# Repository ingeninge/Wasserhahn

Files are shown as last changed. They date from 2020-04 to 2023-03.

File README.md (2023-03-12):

# Wasserhahn

ATTENTION! This repository is only for testing! No production, and never will be.

MQTT controlled Motor Bulb Valve ESP8266 Arduino
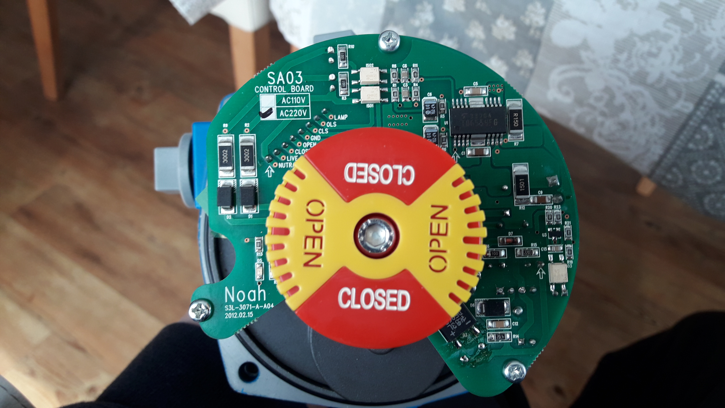
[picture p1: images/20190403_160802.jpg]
Image of the motor driver

Manufactor is END. Here is a link to the Datasheet: https://shop.end.de/armaturen/antriebe-und-zubehoer/elektrische-antriebe/ne034100-elektrischer-schwenkantrieb-30nm-230v-ac

Since my water tap in the garden was leaking and the repair would have included ripping down the building bricks, I asked a friend to build in a ball valve. 
On this I could mount a motor to open and close the garden water tap.
To control the motor I use a ESP8266-12 (WROOM-02) and two relays. The ESP uses 2 Inputs and 2 Outputs.
The schematic can be found in the folder images.
The Inputs are from the auxiliary isolated contacts from the motor. The contacts are closed ONLY at the end position of each turn.br>If both are open the valve is in between open and close.
The Outputs are controlling two relays. One for opening and one for closing the valve. The outputs are held active for 90 seconds.
<br>MQTT- protocol is used to control the garden water tap remotely.
First idea was to let it work with an Arduino Sketch, witch you can find in the sources. But then I figured out how to set up Tasmota to work with this Board and Motor. The workaround is: Tasmota [https://github.com/arendst/Tasmota] (I use Version 7.1) controls 2 relays - one for Opening and one for Closing the tap. The downside is, you will have to use two buttons or configure node-red with a function to control the state and switch between the states.<br>
For Programming see https://www.forward.com.au/pfod/ESP8266/GPIOpins/index.html GPIO0 and RST are on Jumper J5. GPIO2 is permanently pulled up via R8.
Todo: Remove copper under the antenna! Enable access to GPIO15 for programming mode or pull low permanent. update mill and drill files, mill, solder and test the layout. Release to public

The settings for Tasmota can be found in the Wiki https://github.com/ingeninge/Wasserhahn/wiki

BTW: I can control the bulb valve with a remote control in the garden, so I don't have to pull out my mobile to open the tap. [Remote control for Wasserhahn](https://github.com/ingeninge/ESP-Watertap-Remote)

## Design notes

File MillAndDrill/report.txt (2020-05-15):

Plot file "/home/ingmar/Programmieren/Wasserhahn/MillAndDrill/Wasserhahn-B_Cu.gbl" created.
Plot file "/home/ingmar/Programmieren/Wasserhahn/MillAndDrill/Wasserhahn-Edge_Cuts.gm1" created.

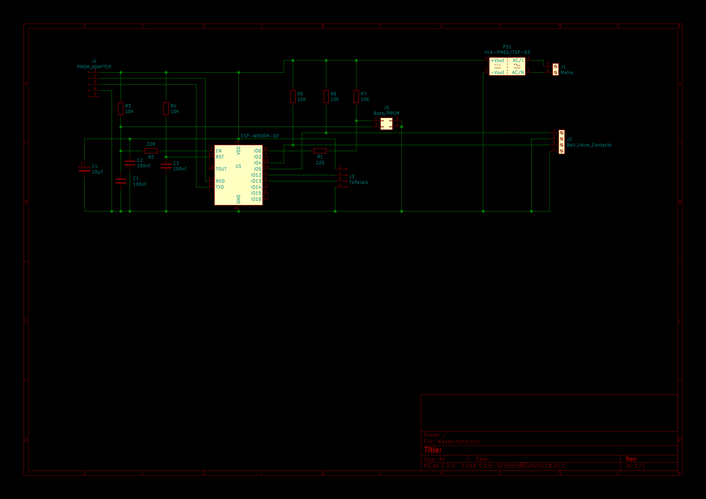
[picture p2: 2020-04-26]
images/Wasserhahn.sch.png

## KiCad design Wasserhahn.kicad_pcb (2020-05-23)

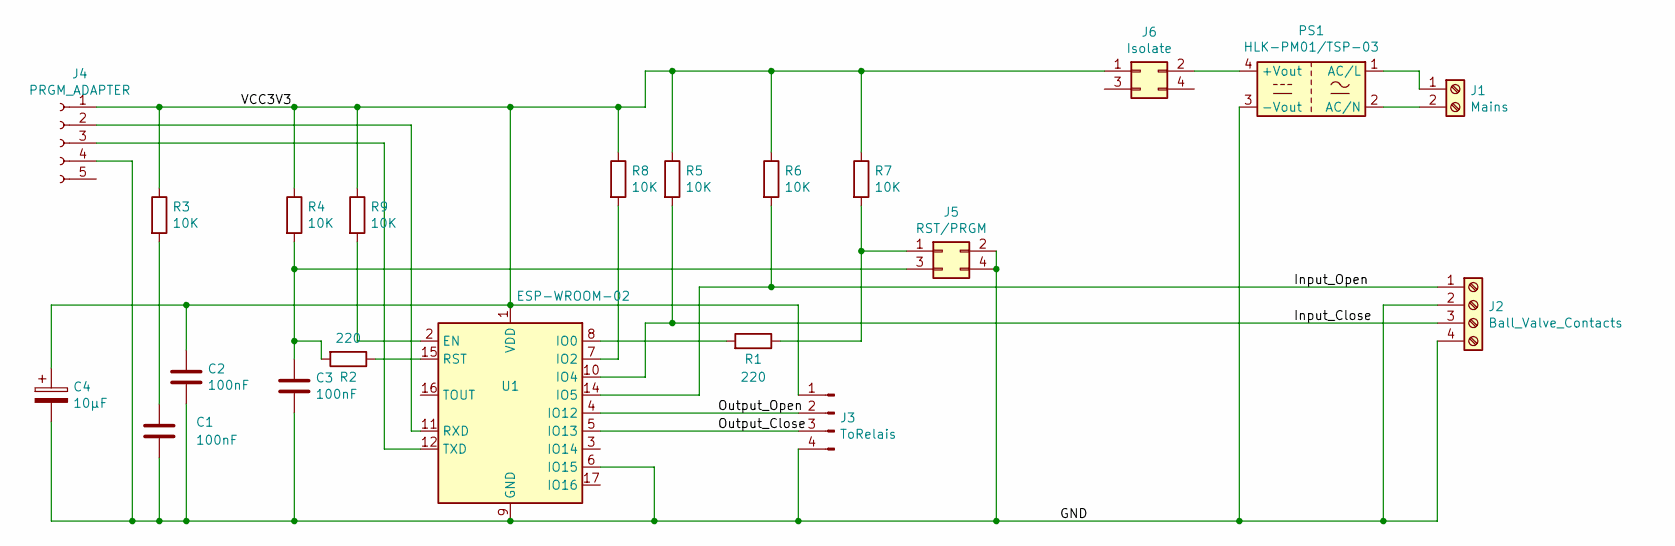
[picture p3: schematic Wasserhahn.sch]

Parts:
C1, C2, C3: 100nF; CP_Radial_D4.0mm_P2.00mm
C4: 10µF; CP_Radial_D6.3mm_P2.50mm
J1: Mains; TerminalBlock_Phoenix_PT-1,5-2-5.0-H_1x02_P5.00mm_Horizontal
J2: Ball_Valve_Contacts; TerminalBlock_Phoenix_PT-1,5-4-5.0-H_1x04_P5.00mm_Horizontal
J3: ToRelais; PinHeader_1x04_P2.54mm_Vertical
J4: PRGM_ADAPTER; PinHeader_1x05_P2.54mm_Vertical
J5: RST/PRGM; PinHeader_2x02_P2.54mm_Vertical
J6: Isolate; PinHeader_2x02_P2.54mm_Vertical
PS1: HLK-PM01/TSP-03; Converter_ACDC_HiLink_HLK-PMxx
R1, R2: 220; R_Axial_DIN0207_L6.3mm_D2.5mm_P10.16mm_Horizontal
R3, R4, R5, R6, R7, R8, R9: 10K; R_Axial_DIN0207_L6.3mm_D2.5mm_P10.16mm_Horizontal
U1: ESP-WROOM-02

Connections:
/GND: C1.2, C2.2, C3.2, C4.2, J2.2, J2.4, J3.4, J4.4, J5.2, J5.4, PS1.3 (-Vout), U1.6 (IO15), U1.9 (GND), U1.13 (GND), U1.18 (GND), U1.19 (GND)
/Input_Close: J2.3, R5.2, U1.10 (IO4)
/Input_Open: J2.1, R6.2, U1.14 (IO5)
/Output_Close: J3.3, U1.5 (IO13)
/Output_Open: J3.2, U1.4 (IO12)
/VCC3V3: C2.1, C4.1, J3.1, J4.1, J6.1, R3.1, R4.1, R5.1, R6.1, R7.1, R8.1, R9.1, U1.1 (VDD)
unnamed: C1.1, R3.2
unnamed: C3.1, J5.3, R2.2, R4.2
unnamed: J1.1, PS1.1 (AC/L)
unnamed: J1.2, PS1.2 (AC/N)
unnamed: J4.2, U1.11 (RXD)
unnamed: J4.3, U1.12 (TXD)
unnamed: J5.1, R1.1, R7.2
unnamed: J6.2, PS1.4 (+Vout)
unnamed: R1.2, U1.8 (IO0)
unnamed: R2.1, U1.15 (RST)
unnamed: R8.2, U1.7 (IO2)
unnamed: R9.2, U1.2 (EN)

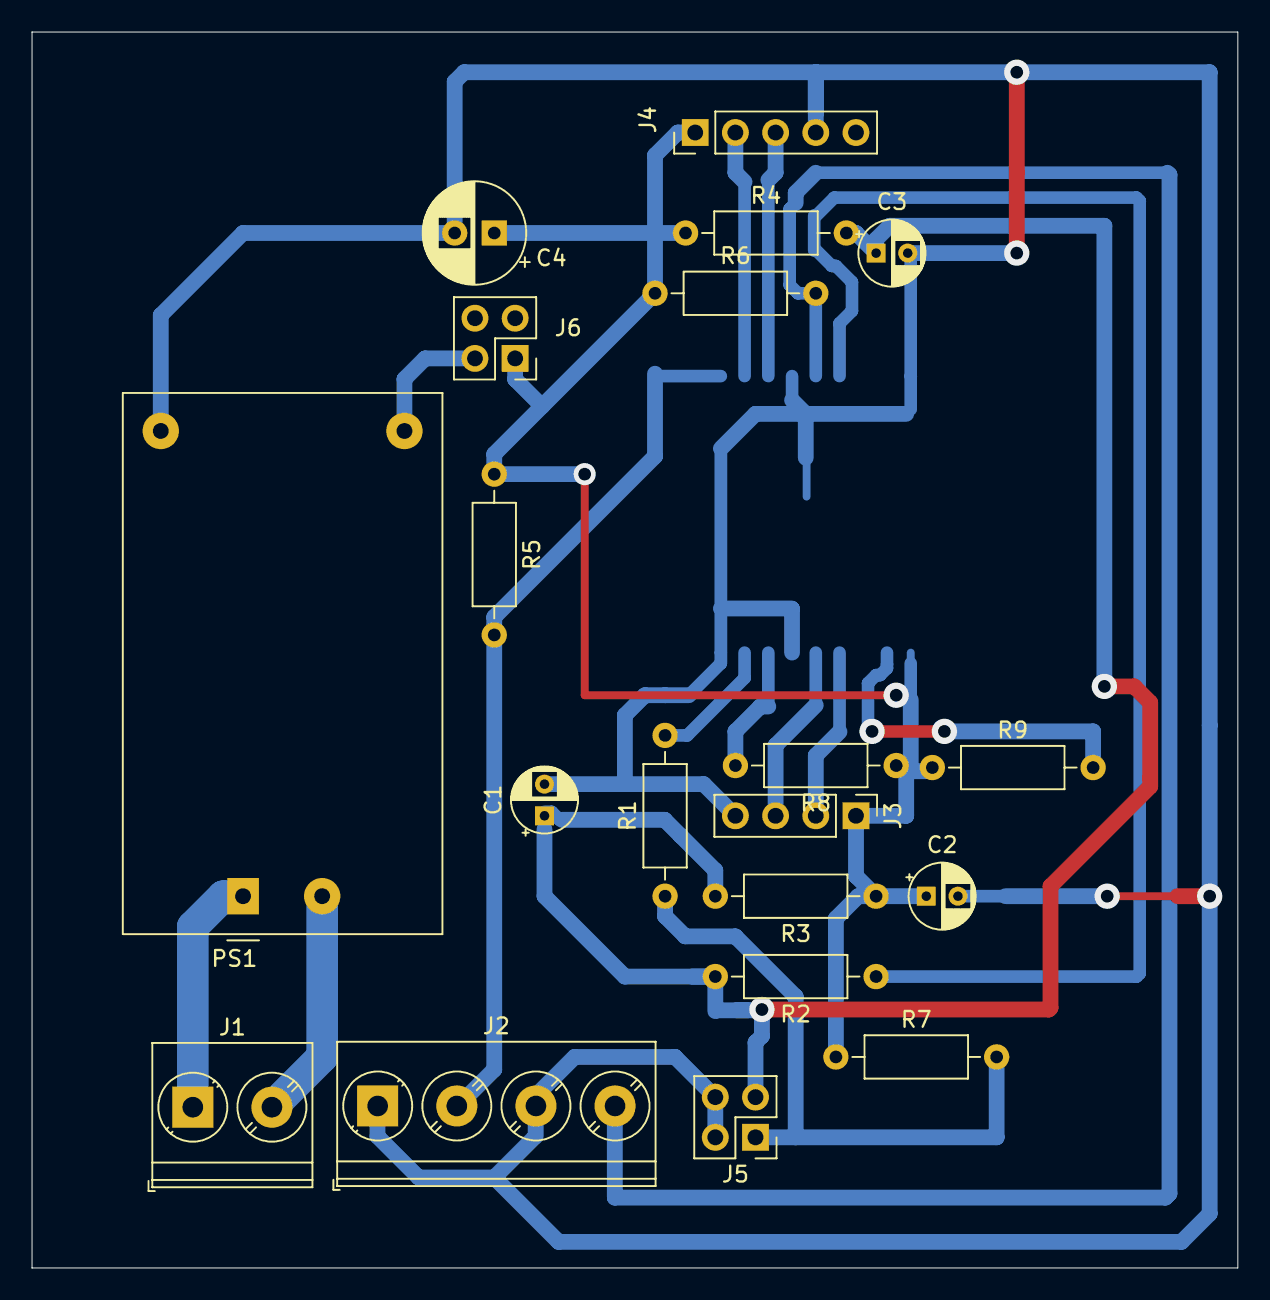
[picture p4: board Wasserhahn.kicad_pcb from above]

Board: 2 copper layers, 76.2 x 78.1 mm, 21 parts (1 on the bottom side), 18 nets.

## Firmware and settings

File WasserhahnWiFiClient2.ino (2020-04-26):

#include <PubSubClient.h>
#include <ESP8266WiFi.h>

/* Used ESP8266 WROOM-02 module from Pollin.de
Pin Name  Function  used_as
10  IO4   GPIO4     Input_Close Wasserhahn geschlossen, wenn auf GND
14  IO5   GPIO5     Input_Open  Wasserhahn geöffnet, wenn auf GND
04  IO12  GPIO12    Output_Open Schaltet das Relay zum Öffnen ein
05  IO13  GPIO13    Output_Close Schaltet das Relay zum Schließen ein

Usage:  mosquitto_pub -h 192.168.2.78 -t wasserhahn/set -m Status // returns a JSON-String: {"Close":0,"Open":1}
        mosquitto_pub -h 192.168.2.78 -t wasserhahn/set -m Close
        mosquitto_pub -h 192.168.2.78 -t wasserhahn/set -m Open

*/

#define INPUT_CLOSE 4
#define INPUT_OPEN 5
#define OUTPUT_OPEN 12
#define OUTPUT_CLOSE 13

#ifndef STASSID
#define STASSID "YourSSID"
#define STAPSK  "YourSecretKey"
#endif
const char* ssid     = STASSID;
const char* password = STAPSK;

char* topic = "wasserhahn/set";
char* server = "192.168.2.78";
char message_buff[100];

const char* host = "192.168.2.78";
const uint16_t port = 1883;
String payload = "";
// Der Motorkugelhahn hat 2 galvanisch getrennte kontakte. Einer schließt bei vollständig geschlossenem Kugelhahn,
// der zweite schließt bei vollständig geöffneten Kugelhahn. Dazwischen sind beide Kontakte offen
int status=0; //Status des Kugelhahns: 0=offen, 1=zu, 2=weder noch (beide Kontakte offen)
long lastReconnectAttempt = 0;

void Open() {
  if(!(digitalRead(INPUT_OPEN))) {
    Serial.println("Wasserhahn ist bereits auf");
    delay(100);
    Status();
    delay(100);
    exit;
  }
  else
  {
    Serial.println("Öffne Wasserhahn");
    while (digitalRead(INPUT_OPEN)) { 
      delay(100);
      digitalWrite(OUTPUT_OPEN, 1);
      //max 90sek
      delay(100);
    }
   }
    Serial.println("Wasserhahn voll geöffnet");
    delay(2000);
    digitalWrite(OUTPUT_OPEN, 0);
    delay(100);
    Status();
    delay(100);
}

void Close() {
  if(!(digitalRead(INPUT_CLOSE))) {
    Serial.println("Wasserhahn ist bereits zu");
    delay(100);
    Status();
    delay(100);
    exit;
  }
  else
  {
    Serial.println("Schließe Wasserhahn");
    while (digitalRead(INPUT_CLOSE)) { 
      delay(100);
      digitalWrite(OUTPUT_CLOSE, 1);
      //max 90sek
      delay(100);
    }
   }
    Serial.println("Wasserhahn voll geschlossen");
    delay(2000);
    digitalWrite(OUTPUT_CLOSE, 0);
    delay(100);
    Status();
    delay(100);
}

void callback(char* topic, byte* payload, unsigned int length) {
  // handle message arrived
  int i = 0;
  Serial.println("Message arrived:  topic: " + String(topic));
  Serial.println("Length: " + String(length,DEC));
  // create character buffer with ending null terminator (string)
  for(i=0; i<length; i++) {
    message_buff[i] = payload[i];
  }
  message_buff[i] = '\0';
  
  String msgString = String(message_buff);
  Serial.println("Payload: " + msgString);
  if (msgString.equals("Open")) {
    Open();
  } else if (msgString.equals("Close")) {
    Close();
  } else if (msgString.equals("Status")) {
    Status();
  }
}



String macToStr(const uint8_t* mac)
{
  String result;
  for (int i = 0; i < 6; ++i) {
    result += String(mac[i], 16);
    if (i < 5)
      result += ':';
  }
  return result;
}

WiFiClient wifiClient;
PubSubClient client(host, 1883, callback, wifiClient);

void setup() {
  //pinMode(pin,mode);
  pinMode(OUTPUT_CLOSE,OUTPUT);
  pinMode(OUTPUT_OPEN,OUTPUT);
  pinMode(INPUT_CLOSE,INPUT);
  pinMode(INPUT_OPEN,INPUT);
  digitalWrite(12,0);
  digitalWrite(13,0); //beide Relais aus
  
  Serial.begin(115200);

  // We start by connecting to a WiFi network

  //Serial.println();
  //Serial.println();
  Serial.print("Connecting to ");
  Serial.println(ssid);

  /* Explicitly set the ESP8266 to be a WiFi-client, otherwise, it by default,
     would try to act as both a client and an access-point and could cause
     network-issues with your other WiFi-devices on your WiFi-network. */
  WiFi.mode(WIFI_STA);
  WiFi.begin(ssid, password);

  while (WiFi.status() != WL_CONNECTED) {
    delay(500);
    Serial.print(".");
  }

  Serial.println("");
  Serial.println("WiFi connected");
  Serial.println("IP address: ");
  Serial.println(WiFi.localIP());
  Serial.println("Connecting to MQTT Broker");
  /*String clientName="Wasserhahn";
  uint8_t mac[6];
  WiFi.macAddress(mac);
  clientName += macToStr(mac);
  clientName += "-";
  clientName += String(micros() & 0xff, 16);

  Serial.print("Connecting to ");
  Serial.print(server);
  Serial.print(" as ");
  Serial.println(clientName);
    if (client.connect((char*) clientName.c_str())) {*/
    if (reconnect()) {
      Serial.println("Connected to MQTT broker");
      Serial.print("Topic is: ");
      Serial.println(topic);
    
      if (client.publish(topic, "hello from ESP8266")) {
        Serial.println("Publish ok");
      }
      else {
        Serial.println("Publish failed");
      }
    }
    else {
      Serial.println("MQTT connect failed");
      Serial.println("Will reset and try again...");
      abort();
    }
  if (client.connected()){
    Serial.print("Sending payload: ");
    Serial.println(payload);
    if (client.subscribe("wasserhahn/set")) {
      Serial.println("Subscripe OK");
    }
    else {
      Serial.println("Subscription failed");
    }
  }
}

void Status() {
  //create a JSON string
  payload = "{\"Close\":";
  payload += digitalRead(INPUT_CLOSE);
  payload += ",\"Open\":";
  payload += digitalRead(INPUT_OPEN);
  payload += "}";
  Serial.println("Status: " + payload);
  if (client.publish(topic, (char*) payload.c_str())) {
      Serial.println("Publish ok");
    }
    else {
      Serial.println("Publish failed Status()" +payload);
    }
    Serial.println("Ende Status()");
}

boolean reconnect() {
  String clientName="Wasserhahn";
  uint8_t mac[6];
  WiFi.macAddress(mac);
  clientName += macToStr(mac);
  clientName += "-";
  clientName += String(micros() & 0xff, 16);
  if (client.connect((char*) clientName.c_str())) {
    // Once connected, publish an announcement...
    client.publish("wasserhahn/set","reconnect");
    // ... and resubscribe
    client.subscribe("wasserhahn/set");
  }
  return client.connected();
}

void loop() {
  if (!client.connected()) {
    long now = millis();
    if (now - lastReconnectAttempt > 5000) {
      lastReconnectAttempt = now;
      // Attempt to reconnect
      if (reconnect()) {
        lastReconnectAttempt = 0;
        Serial.println("reconnected");
      }
    }
  } else {
    // Client connected

   //static int counter = 0;
  client.loop();
  //++counter;
  delay(50);
  }
  }

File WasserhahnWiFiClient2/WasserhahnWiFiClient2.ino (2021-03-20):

#include <ESP8266WiFi.h>
#include <PubSubClient.h>

/* Used ESP8266 WROOM-02 module from Pollin.de
Pin Name  Function  used_as
10  IO4   GPIO4     Input_Close Wasserhahn geschlossen, wenn auf GND
14  IO5   GPIO5     Input_Open  Wasserhahn geöffnet, wenn auf GND
04  IO12  GPIO12    Output_Open Schaltet das Relay zum Öffnen ein
05  IO13  GPIO13    Output_Close Schaltet das Relay zum Schließen ein

If you are testing on a NodeMCU Dev-Board: 
D1 = GPIO5
D2 = GPIO4
D6 = GPIO12
D7 = GPIO13

Usage:  mosquitto_pub -h your.mqtt.broker.ip -t wasserhahn/set -m Status // returns a JSON-String: {"Close":0,"Open":1}
        mosquitto_pub -h your.mqtt.broker.ip -t wasserhahn/set -m Close
        mosquitto_pub -h your.mqtt.broker.ip -t wasserhahn/set -m Open
*/

#define INPUT_CLOSE 4
#define INPUT_OPEN 5
#define OUTPUT_OPEN 12
#define OUTPUT_CLOSE 13

#define DEBUGSERIAL

// Put your credentials for your WiFi either in a file called credentials.h in your project folder or below
#ifdef DEBUGSERIAL
  #include "credentials.h"
#endif

// WiFi Settings if not using credentials.h
#ifndef STASSID
//#define STASSID "YourSSID"
//#define STAPSK  "YourSecretKey"
#endif
const char* ssid     = STASSID;
const char* password = STAPSK;


// MQTT Broker Settings
//const char* server = "your.mqtt.broker.ip";
const char* server = "192.168.2.78";
const uint16_t port = 1883;
// change this to the mqtt topic you want to use:
char* topic = "wasserhahn2/set";
String clientName="wasserhahn2";
char message_buff[100];
String payload = "";

// Der Motorkugelhahn hat 2 galvanisch getrennte kontakte. Einer schließt bei vollständig geschlossenem Kugelhahn,
// der zweite schließt bei vollständig geöffneten Kugelhahn. Dazwischen sind beide Kontakte offen.
// The ball valve has 2 isolated contacts. Only one contact at a time is closed. In transient phase both are open.

int status=0; //Status des Kugelhahns: 0=offen/open, 1=zu/closed, 2=weder noch (beide Kontakte offen)/both contacts open

long lastReconnectAttempt = 0;

void Open() {
  if(!(digitalRead(INPUT_OPEN))) {
    #ifdef DEBUGSERIAL
    Serial.println("Wasserhahn ist bereits auf");
    //Serial.println("Valve is already open");
    #endif
    delay(100);
    Status();
    delay(100);
    exit;
  }
  else
  { 
    #ifdef DEBUGSERIAL
    Serial.println("Öffne Wasserhahn");
    //Serial.println("Opening valve");
    #endif
    while (digitalRead(INPUT_OPEN)) { 
      delay(100);
      digitalWrite(OUTPUT_OPEN, 1);
      //needs max 90s
      delay(100);
    }
   }
    #ifdef DEBUGSERIAL
    Serial.println("Wasserhahn voll geöffnet");
    //Serial.println("Opening completed");
    #endif
    delay(2000);
    digitalWrite(OUTPUT_OPEN, 0);
    delay(100);
    Status();
    delay(100);
}

void Close() {
  if(!(digitalRead(INPUT_CLOSE))) {
    #ifdef DEBUGSERIAL
    Serial.println("Wasserhahn ist bereits zu");
    //Serial.println("Valve is already closed");
    #endif
    delay(100);
    Status();
    delay(100);
    exit;
  }
  else
  {
    #ifdef DEBUGSERIAL
    Serial.println("Schließe Wasserhahn");
    //Serial.println("Closeing valve");
    #endif
    while (digitalRead(INPUT_CLOSE)) { 
      delay(100);
      digitalWrite(OUTPUT_CLOSE, 1);
      //max 90sek
      delay(100);
    }
   }
    #ifdef DEBUGSERIAL
    Serial.println("Wasserhahn voll geschlossen");
    //Serial.println("Closeing completed");
    #endif
    delay(2000);
    digitalWrite(OUTPUT_CLOSE, 0);
    delay(100);
    Status();
    delay(100);
}

void callback(char* topic, byte* payload, unsigned int length) {
  // Rückrufroutine für MQTT Nachrichten / handle message arrived
  int i = 0;
  #ifdef DEBUGSERIAL
  Serial.println("Message arrived:  topic: " + String(topic));
  Serial.println("Length: " + String(length,DEC));
  #endif
  // create character buffer with ending null terminator (string)
  for(i=0; i<length; i++) {
    message_buff[i] = payload[i];
  }
  message_buff[i] = '\0';
  
  String msgString = String(message_buff);
  #ifdef DEBUGSERIAL
  Serial.println("Payload: " + msgString);
  #endif
  if (msgString.equals("Open")) {
    Open();
  } else if (msgString.equals("Close")) {
    Close();
  } else if (msgString.equals("Status")) {
    Status();
  }
}

WiFiClient wifiClient;
PubSubClient client(server, 1883, callback, wifiClient);

void Status() {
  //create a JSON string
  payload = "{\"Close\":";
  payload += digitalRead(INPUT_CLOSE);
  payload += ",\"Open\":";
  payload += digitalRead(INPUT_OPEN);
  payload += "}";
  #ifdef DEBUGSERIAL
  Serial.println("Status: " + payload);
  #endif
  if (client.publish(topic, (char*) payload.c_str())) {
      #ifdef DEBUGSERIAL
      Serial.println("Publish ok");
      #endif
    }
    else {
      #ifdef DEBUGSERIAL
      Serial.println("Publish failed Status()" +payload);
      #endif
    }
    #ifdef DEBUGSERIAL
    Serial.println("Ende Status()");
    #endif
}

String macToStr(const uint8_t* mac)
{
  String result;
  for (int i = 0; i < 6; ++i) {
    result += String(mac[i], 16);
    if (i < 5)
      result += ':';
  }
  return result;
}

boolean reconnect() {
  String clientName = String(topic);
  uint8_t mac[6];
  WiFi.macAddress(mac);
  //clientName += topic;
  clientName += macToStr(mac);
  clientName += "-";
  clientName += String(micros() & 0xff, 16);
  if (client.connect((char*) clientName.c_str())) {
    // Once connected, publish an announcement...
    client.publish(topic,"reconnect");
    // ... and resubscribe
    client.subscribe(topic);
  }
  return client.connected();
}
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

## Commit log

2020-04-26 Added Schematics in KiCAD Format, added outlines and milling files in g-code made with Flatcam.
    [Wasserhahn.kicad_pcb, Wasserhahn.sch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]
2020-04-26 Addes pictures of the Motor
2020-04-26 Added Arduino ino file and a picture of the schematic
2020-04-26 Updated Board and Plot data
    [Wasserhahn.kicad_pcb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]
2020-05-15 optimized path in flatcam and widened the track width in kiCad
    [Wasserhahn.kicad_pcb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]
2020-05-16 width change for bigger tracks
    [Wasserhahn.kicad_pcb]
2020-05-16 added connections for IO2, removed short circuit, swaped EN and RST on Jumper
    [Wasserhahn.kicad_pcb, Wasserhahn.sch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]
2020-05-23 GPIO15 pulled low, jumper to disconnect Power for flashing
    [Wasserhahn.kicad_pcb, Wasserhahn.sch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]
